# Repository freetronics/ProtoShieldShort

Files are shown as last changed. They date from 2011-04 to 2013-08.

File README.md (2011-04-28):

Freetronics ProtoShieldShort
==============================
Copyright 2011 Freetronics Pty Ltd  
Freetronics site:  <www.freetronics.com>  
Freetronics email: <info@freetronics.com>  

A special short prototyping shield for the Arduino, designed to be able
to clear the RJ45 jack on an Ethernet Shield or Freetronics EtherTen.

Note that this design is intended for simple fabrication and assembly,
and does not have many of the features of other prototyping shields
such as the "ProtoShield" (also available from Freetronics) such as
general-purpose LEDs.

Features:

 * Pads for reset button connected to Arduino reset pin.
 * Parts overlay on both the top and the bottom so you can see what you
   are connecting without having to keep turning the board over.

More information is available at:

  http://www.freetronics.com/protoshield-short

The "docs" folder within this repository includes a handy copy of the
schematic in PDF format and image(s) of the pcb.

INSTALLATION
------------
The design is saved as an EAGLE project. EAGLE PCB design software is
available from www.cadsoftusa.com free for non-commercial use. To use
this project download it and place the directory containing these files
into the "eagle" directory on your computer. Then open EAGLE and
navigate to Projects -> eagle -> ProtoShieldShort.

DISTRIBUTION
------------
The specific terms of distribution of this project are governed by the
license referenced below.

LICENSE
-------
Licensed under the TAPR Open Hardware License (www.tapr.org/OHL).
The "license" folder within this repository also contains a copy of
this license in plain text format.

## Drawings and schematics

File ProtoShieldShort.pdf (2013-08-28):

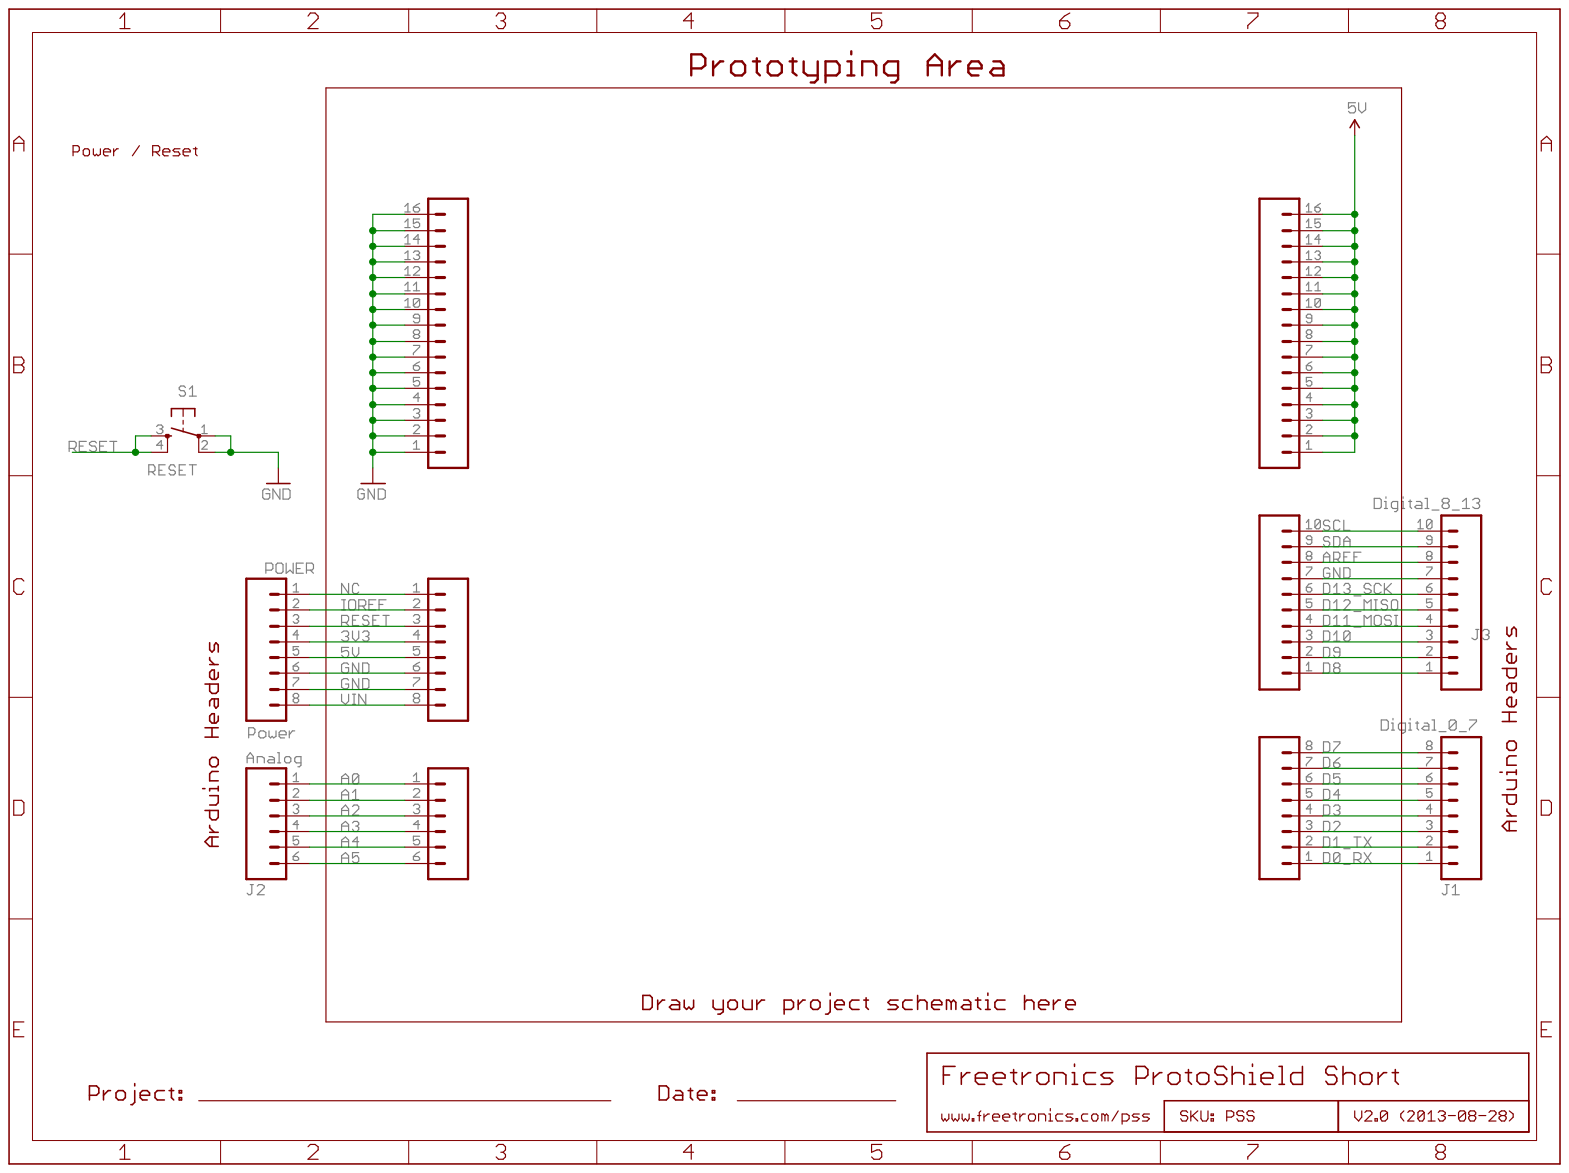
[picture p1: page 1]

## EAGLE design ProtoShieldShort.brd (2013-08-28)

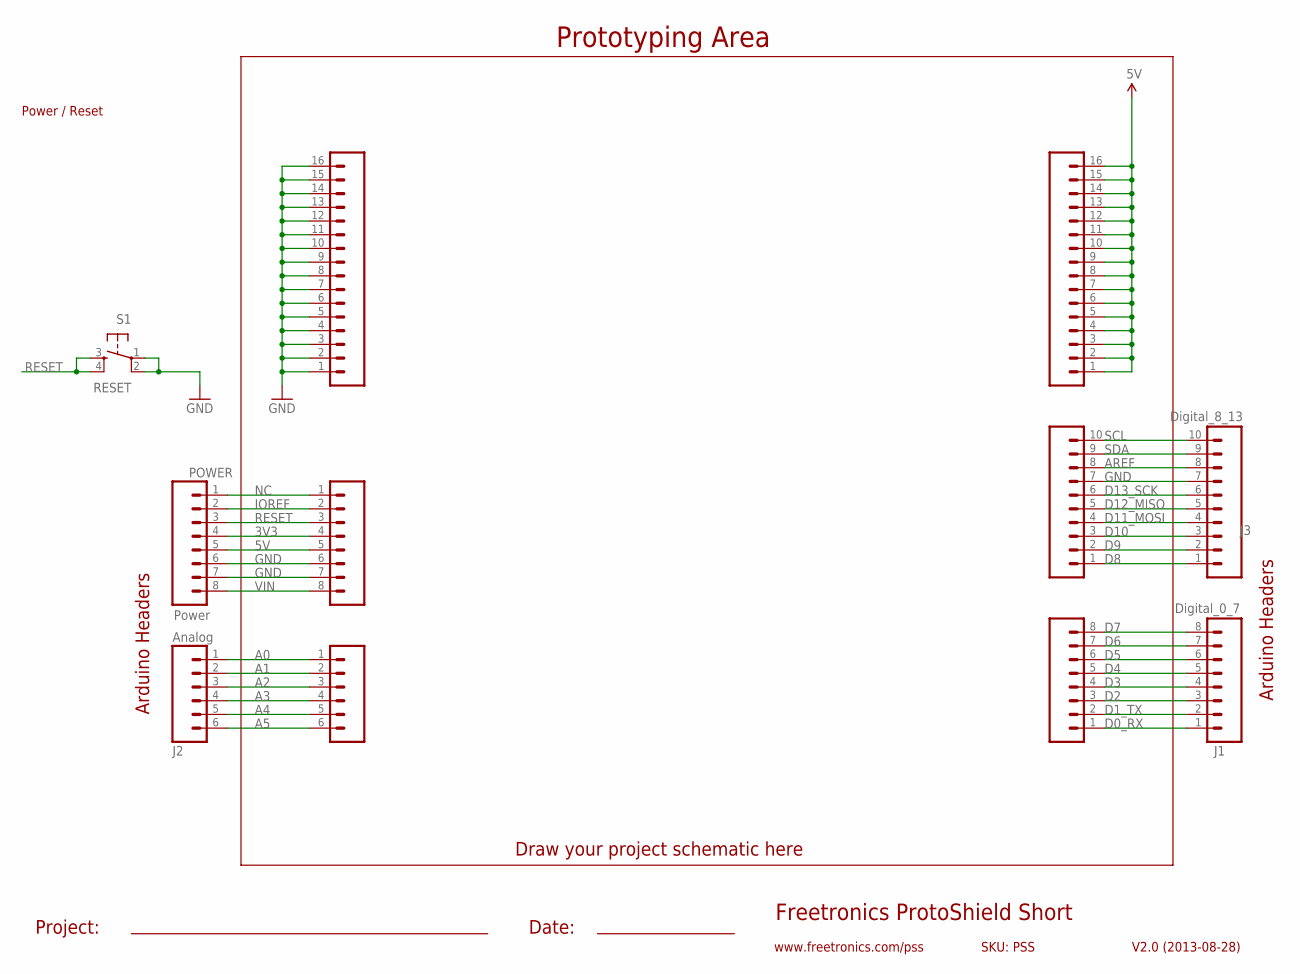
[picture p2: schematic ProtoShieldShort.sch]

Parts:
J1: Digital_0_7; 1X08
J2: Analog; 1X06
J3: Digital_8_13; 1X10
PADS_5V: M16PTH; 1X16
PADS_GND: M16PTH; 1X16
POWER: Power; 1X08
S1: RESET; TACTILE-PTH
SL1: Digital_0_7; 1X08
SL2: Analog; 1X06
SL3: Digital_8_13; 1X10
SLP: Power; 1X08

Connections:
3V3: POWER.4, SLP.4
5V: PADS_5V.1, PADS_5V.2, PADS_5V.3, PADS_5V.4, PADS_5V.5, PADS_5V.6, PADS_5V.7, PADS_5V.8, PADS_5V.9, PADS_5V.10, PADS_5V.11, PADS_5V.12, PADS_5V.13, PADS_5V.14, PADS_5V.15, PADS_5V.16, POWER.5, SLP.5
A0: J2.1, SL2.1
A1: J2.2, SL2.2
A2: J2.3, SL2.3
A3: J2.4, SL2.4
A4: J2.5, SL2.5
A5: J2.6, SL2.6
AREF: J3.8, SL3.8
D0_RX: J1.1, SL1.1
D1_TX: J1.2, SL1.2
D2: J1.3, SL1.3
D3: J1.4, SL1.4
D4: J1.5, SL1.5
D5: J1.6, SL1.6
D6: J1.7, SL1.7
D7: J1.8, SL1.8
D8: J3.1, SL3.1
D9: J3.2, SL3.2
D10: J3.3, SL3.3
D11_MOSI: J3.4, SL3.4
D12_MISO: J3.5, SL3.5
D13_SCK: J3.6, SL3.6
GND: J3.7, PADS_GND.1, PADS_GND.2, PADS_GND.3, PADS_GND.4, PADS_GND.5, PADS_GND.6, PADS_GND.7, PADS_GND.8, PADS_GND.9, PADS_GND.10, PADS_GND.11, PADS_GND.12, PADS_GND.13, PADS_GND.14, PADS_GND.15, PADS_GND.16, POWER.6, POWER.7, S1.1, S1.2, SL3.7, SLP.6, SLP.7
IOREF: POWER.2, SLP.2
NC: POWER.1, SLP.1
RESET: POWER.3, S1.3, S1.4, SLP.3
SCL: J3.10, SL3.10
SDA: J3.9, SL3.9
VIN: POWER.8, SLP.8

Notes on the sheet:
Freetronics ProtoShield Short
V2.0 (2013-08-28)
www.freetronics.com/pss
SKU: PSS
Prototyping Area
Arduino Headers
Power / Reset
Project:
Date:
Draw your project schematic here

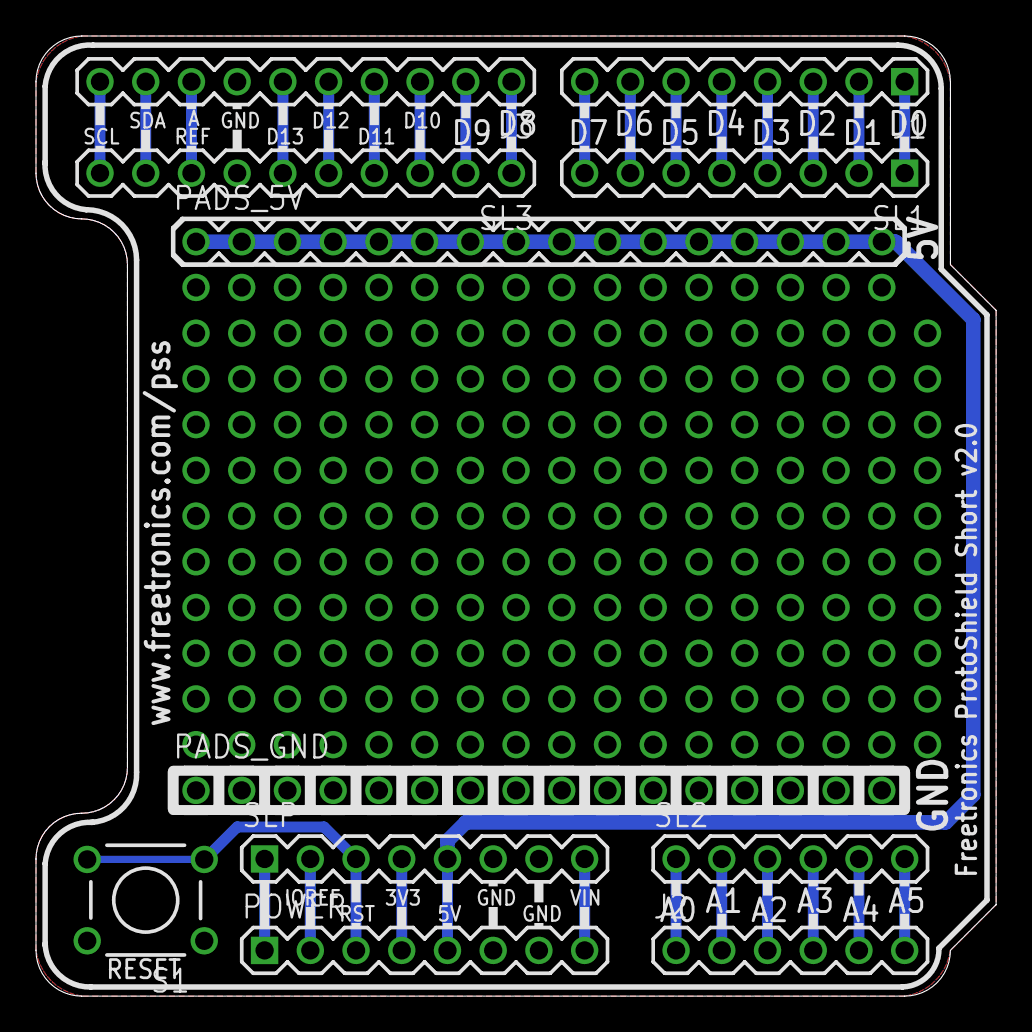
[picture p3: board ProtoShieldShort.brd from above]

Board: 2 copper layers, 53.3 x 53.3 mm, 11 parts (0 on the bottom side), 30 nets.

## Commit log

2011-04-28 Added initial project files
    [ProtoShieldShort.brd, ProtoShieldShort.sch]
2013-08-28 Updates to R3 headers and v2.0 release
    [ProtoShieldShort.brd, ProtoShieldShort.sch]

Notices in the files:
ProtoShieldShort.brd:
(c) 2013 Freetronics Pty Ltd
